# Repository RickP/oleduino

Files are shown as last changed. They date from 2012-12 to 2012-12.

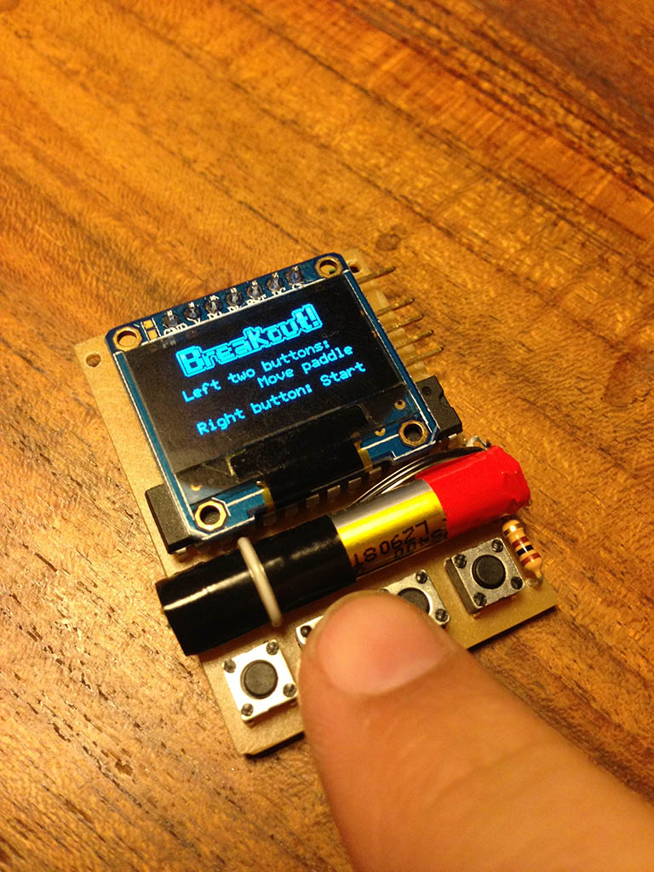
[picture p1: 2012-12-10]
Assembled_Device.jpg

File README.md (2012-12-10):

OLEDuino
--------

A cheap electronic name badge that can be programmed with the arduino ide. 
The ATMEGA 328 has to be preloaded with the Arduino Pro 8Mhz 3.3V bootloader.
Also chose that board when programming the badge with a 3.3V FTDI board.

All the analog ports are available for addons. 

* A source for the OLED: Search eBay for "128X64 OLED module" and pick the cheapest one with the 7 pin header on top
* A source for a battery: Any small 3.7V lithium polymer battery will do (like the ones for small RC helicopters)
* A source for the charger: http://www.ebay.com/itm/260581913847

OLEDuino

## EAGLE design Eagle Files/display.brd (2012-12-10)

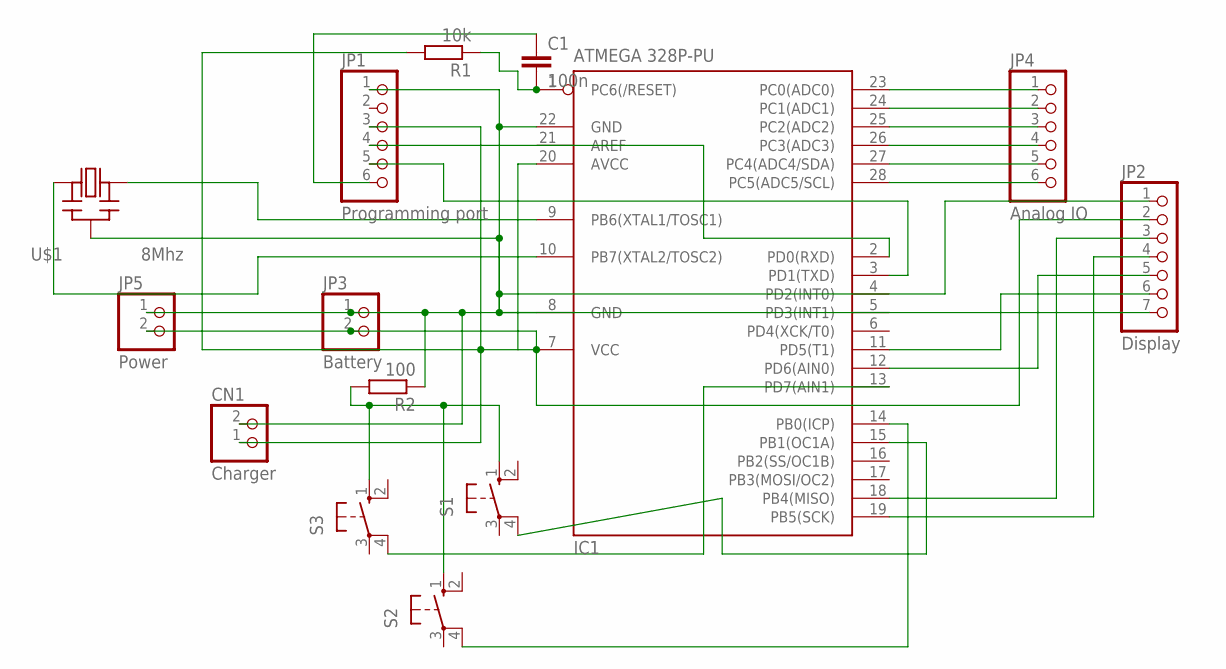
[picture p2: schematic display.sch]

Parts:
C1: 100n; C050-025X075
CN1: Charger; JST-PH-2-THM-RA
IC1: ATMEGA 328P-PU; DIL28-3
JP1: Programming port; 1X06/90
JP2: Display; 1X07
JP3: Battery; 1X02
JP4: Analog IO; 1X06-CLEAN
JP5: Power; 1X02
R1: 10k; 0204/7
R2: 100; 0204/7
S1, S3: 10-XX; B3F-10XX
S2: 10-XX; B3F-10XX; MPN B3F-1000
U$1: 8Mhz; CERM_OSC

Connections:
unnamed: IC1.23 (PC0(ADC0)), JP4.1
unnamed: IC1.10 (PB7(XTAL2/TOSC2)), U$1.P$1 (IN)
unnamed: IC1.19 (PB5(SCK)), JP2.4
unnamed: C1.2, IC1.1 (PC6(/RESET)), R1.1
unnamed: IC1.2 (PD0(RXD)), JP1.4
unnamed: IC1.3 (PD1(TXD)), JP1.5
unnamed: IC1.18 (PB4(MISO)), JP2.3
unnamed: CN1.1 (2), IC1.7 (VCC), IC1.20 (AVCC), JP1.3, JP2.2, JP3.2, JP5.2, R1.2
unnamed: IC1.15 (PB1(OC1A)), S1.4 (P1)
unnamed: IC1.13 (PD7(AIN1)), S3.4 (P1)
unnamed: C1.1, JP1.6
unnamed: R2.2, S1.1 (S), S2.1 (S), S3.1 (S)
unnamed: IC1.12 (PD6(AIN0)), JP2.5
unnamed: IC1.9 (PB6(XTAL1/TOSC1)), U$1.P$3 (OUT)
unnamed: IC1.11 (PD5(T1)), JP2.6
unnamed: IC1.14 (PB0(ICP)), S2.4 (P1)
unnamed: IC1.28 (PC5(ADC5/SCL)), JP4.6
unnamed: IC1.27 (PC4(ADC4/SDA)), JP4.5
unnamed: IC1.26 (PC3(ADC3)), JP4.4
unnamed: IC1.25 (PC2(ADC2)), JP4.3
unnamed: IC1.24 (PC1(ADC1)), JP4.2
unnamed: CN1.2 (1), IC1.8 (GND), IC1.22 (GND), JP1.1, JP2.1, JP2.7, JP3.1, JP5.1, R2.1, U$1.P$2 (GND)

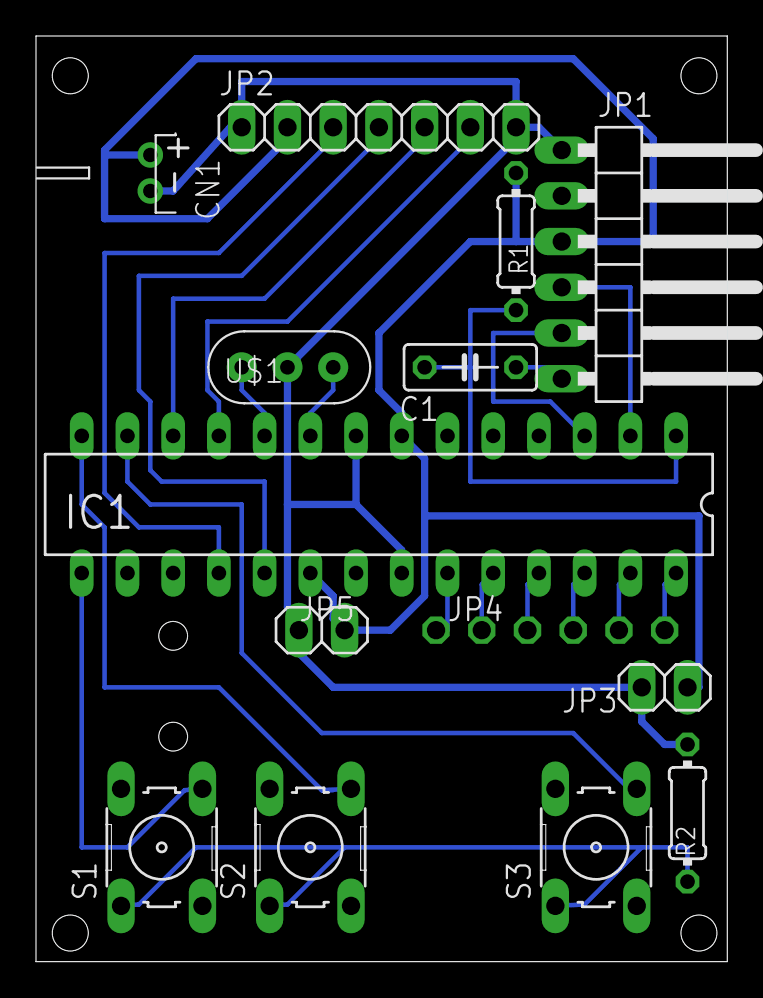
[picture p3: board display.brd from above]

Board: 2 copper layers, 38.4 x 51.4 mm, 14 parts (0 on the bottom side), 22 nets.

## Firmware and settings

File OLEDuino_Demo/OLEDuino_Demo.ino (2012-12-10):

 /*
 OLEDuino Demo
 Copyright (C) 2012 Rick Pannen

 The Breakout game is ported from Sebastian Goscik's version for hackvision

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
 
 This needs the u8glib from http://code.google.com/p/u8glib
 */

#include "U8glib.h"

U8GLIB_SSD1306_128X64 u8g(U8G_PIN_NONE, 5, 6);

const uint8_t title_1[] U8G_PROGMEM = {
0x00,0x07,0xFF,0x80,0x00,0x00,0x00,0x00,0x00,0x00,0x00,0x00,0x03,0xE0,0x00,
0x00,0x08,0x00,0x60,0x00,0x00,0x00,0x1F,0x00,0x00,0x00,0x03,0xF4,0x10,0x00,
0x00,0x0B,0xFF,0x10,0x00,0x00,0x00,0x20,0x80,0x00,0x00,0x04,0x09,0xD0,0x00,
0x00,0x0B,0x83,0xD0,0x00,0x00,0x00,0x2E,0xB8,0x00,0x00,0x05,0xE1,0xD0,0x00,
0x00,0x0B,0x83,0xD0,0x00,0x00,0x00,0x2E,0x44,0x00,0x00,0x05,0xE1,0xD0,0x00,
0x00,0x0B,0x83,0xD0,0x00,0x00,0x00,0x2E,0x34,0x00,0x00,0x05,0xE1,0xD0,0x00,
0x00,0x0B,0x83,0xCF,0xFF,0xF9,0xFF,0xAE,0x35,0xFF,0x7C,0xF9,0xE1,0xD0,0x00,
0x00,0x0B,0x83,0xC0,0x00,0x06,0x00,0x4E,0x66,0x00,0x83,0x01,0xE1,0xD0,0x00,
0x00,0x0B,0xFF,0x13,0xE7,0xF0,0xFF,0x0F,0xE0,0x7E,0x38,0x73,0xF9,0xD0,0x00,
0x00,0x0B,0xFF,0x13,0xE7,0xF0,0xFF,0x0F,0xC0,0x7E,0x38,0x73,0xF9,0xD0,0x00,
0x00,0x0B,0x83,0xDC,0x0E,0x0C,0x01,0xCF,0x80,0xE1,0x38,0x71,0xE1,0xD0,0x00,
0x00,0x0B,0x83,0xDC,0xCE,0x0C,0x01,0xCF,0xC0,0xE1,0x38,0x71,0xE1,0xD0,0x00,
0x00,0x0B,0x83,0xDD,0x2F,0xF0,0x7F,0xCE,0xE0,0xE1,0x38,0x71,0xE0,0x10,0x00,
0x00,0x0B,0x83,0xDD,0x2F,0xF0,0xFF,0xCE,0x70,0xE1,0x38,0x71,0xE0,0x10,0x00,
0x00,0x0B,0x83,0xDD,0x2E,0x00,0x81,0xCE,0x38,0xE1,0x38,0x71,0xE1,0xD0,0x00,
0x00,0x0B,0xFF,0x1D,0x27,0xFC,0xFE,0xCE,0x1C,0x7E,0x1F,0xC4,0x79,0xD0,0x00,
0x00,0x0B,0xFF,0x1D,0x17,0xFC,0x7E,0xCE,0x0C,0x7E,0x1F,0xCA,0x79,0xD0,0x00,
0x00,0x08,0x00,0x41,0x10,0x01,0x00,0x00,0xE1,0x00,0xC0,0x11,0x00,0x10,0x00,
0x00,0x07,0xFF,0xBE,0x0F,0xFE,0xFF,0xFF,0x1E,0xFF,0x3F,0xE0,0xFF,0xE0,0x00,
};

int leftButton = 9;
int rightButton = 8;
int enterButton = 7;

const byte width = 128;   //Width of screen
const byte height = 64;   //Hight of screen
int dx = -1;              //Initial movement of ball
int dy = -1;              //Initial movement of ball
int xb;                   //Balls starting possition
int yb;                   //Balls starting possition
boolean released;         //If the ball has been released by the player
byte xPaddle;             //X position of paddle
boolean isHit[5][12];     //Array of if bricks are hit or not
boolean bounced=false;    //Used to fix double bounce glitch
byte lives = 3;           //Amount of lives
byte level = 1;           //Current level
unsigned int score=0;     //Score for the game
unsigned int brickCount;  //Amount of bricks hit
byte pad1,pad2,pad3;       //Button press buffer used to stop pause repeating
byte oldpad1,oldpad2,oldpad3;
char text[16];            //General string buffer
boolean start=false;      //If in menu or in game
boolean gamemode=false;      //If in menu or in game
boolean initialDraw=false;//If the inital draw has happened
char initials[3];         //Initials used in high score
int divisor = 2;
int moveStep = 0;
int stringPos = 0;

//Ball Bounds used in collision detection
byte leftBall;
byte rightBall;
byte topBall;
byte bottomBall;

//Brick Bounds used in collision detection
byte leftBrick;
byte rightBrick;
byte topBrick;
byte bottomBrick;

long lastKeypress;

int lastButtonState;    // the debounce time;

void setup()
{ 
  pinMode(leftButton, INPUT);
  digitalWrite(leftButton, HIGH);
  pinMode(rightButton, INPUT);
  digitalWrite(rightButton, HIGH);
  pinMode(enterButton, INPUT);
  digitalWrite(enterButton, HIGH);
  
}

void movePaddle()
{
  //Move right
  if(xPaddle < width-20)
  {
    if(!digitalRead(rightButton))
    {  
      xPaddle++;
      lastKeypress = millis();
    }
  }

  //Move left
  if(xPaddle > 0)
  {
    if(!digitalRead(leftButton))
    {  
      xPaddle--;
      lastKeypress = millis();
    }
  } 
}

void moveBall()
{
  if(released)
  {
    //Move ball
    xb=xb + dx;
    yb=yb + dy;

    //Set bounds
    leftBall = xb;
    rightBall = xb+2;
    topBall = yb;
    bottomBall = yb+2;

    //Bounce off top edge
    if (yb<=0)
    {
      yb=2;
      dy=-dy;
    }

    //Lose a life if bottom edge hit
    if (yb>=70)
    {
      xPaddle = 54;
      yb=60; 
      released = false;
      lives--;
      drawLives();
      if (random(0, 2) == 0) {
        dx = 1;
      } 
      else {
        dx = -1;
      }
    }

    //Bounce off left side
    if (xb<=0)
    {
      xb=2;
      dx=-dx;
    }

    //Bounce off right side
    if (xb>=width-2)
    {
      xb=width-4;
      dx=-dx;
    }
    //Bounce off paddle
    if (xb+1>=xPaddle && xb<=xPaddle+20 && yb+2==63){
      dy=-dy;
      dx=((xb-(xPaddle+10))/2); //Applies spin on the ball
    }

    //Bounce off Bricks
    for (byte row = 0; row < 3; row++) {
      for (byte column = 0; column < 12; column++) {
        if (!isHit[row][column]){

          //Sets Brick bounds
          leftBrick = 10*column;
          rightBrick = 10*column+10;
          topBrick = 6*row+6;
          bottomBrick = 6*row+13;

          //If A collison has occured
          if (topBall <= bottomBrick && bottomBall>=topBrick && leftBall<=rightBrick && rightBall >=leftBrick){
            brickCount++;
            score += (level*10);
            isHit[row][column] = true;
            u8g.setColorIndex(1);
            u8g.drawBox(10*column ,2+6*row,8,4);

            //Vertical collision
            if (bottomBall>bottomBrick || topBall<topBrick){
              //Only bounce once each ball move
              if(!bounced){
                dy=-dy;
                yb+=dy;
                bounced=true;
              } 
            }

            //Hoizontal collision
            if (leftBall<leftBrick || rightBall>rightBrick){

              //Only bounce once brick each ball move
              if(!bounced){
                dx=-dx;
                xb+=dx;
                bounced=true;
              } 
            }
          }
        }
      }
    }
    //Reset Bounce
    bounced=false;
  }
  else{
    //Ball follows paddle
    xb=xPaddle+9;

    //Release ball if FIRE pressed
    pad3 = !digitalRead(enterButton);
    if(pad3 == 1 && oldpad3==0){  
      released=true;
      lastKeypress = millis();
      
      //Apply random direction to ball on release
      if (random(0, 2) == 0) {
        dx = 1;
      } 
      else {
        dx = -1;
      }
      //Makes sure the ball heads upwards 
      dy = -1;
    }
    oldpad3=pad3; 
  }
}

void drawBall()
{
  if (moveStep++ > divisor) {
    moveBall();
    moveStep = 0;
  }

  u8g.setColorIndex(1);
  u8g.drawPixel(xb,yb);
  u8g.drawPixel(xb+1,yb);
  u8g.drawPixel(xb,yb+1);
  u8g.drawPixel(xb+1,yb+1);
}

void drawPaddle()
{
  movePaddle();
  u8g.setColorIndex(1);
  u8g.drawBox(xPaddle,63,19,1);
}

void drawLives()
{
  sprintf(text, "LIVES:%u", lives);
  u8g.setColorIndex(1);
  u8g.setFont(u8g_font_04b_24);
  u8g.drawStr(0, 5, text);
}

void drawGameOver()
{
  u8g.setColorIndex(1);
  u8g.setFont(u8g_font_04b_24);
  u8g.drawStr(52, 54, "Game Over");
}

void drawScore()
{
  sprintf(text, "SCORE:%u", score);
  u8g.setColorIndex(1);
  u8g.setFont(u8g_font_04b_24);
  u8g.drawStr(80, 5, text);
}

void newLevel(){
  //Alter various variables to reset the game
  xPaddle = 50;
  yb=60;
  brickCount=0;
  released=false;
  
  //resets their values
  u8g.setColorIndex(1);
  for (byte row = 0; row < 3; row++) {
    for (byte column = 0; column < 12; column++) {
      isHit[row][column] = false;
    }
  }
}

void drawBricks() {
  u8g.setColorIndex(1);
  for (byte row = 0; row < 3; row++) {
    for (byte column = 0; column < 12; column++) {
      if (!isHit[row][column]) {
        u8g.drawBox(10*column ,6+6*row,8,4);
      }
    }
  }
}

boolean titleScreen() {
  
  u8g.setColorIndex(1);
  //Draws the main title
  u8g.drawBitmapP(4, 0, 15, 19, title_1);

  u8g.setColorIndex(1);
  if (score > 0) {
    u8g.setFont(u8g_font_tpssb);
    u8g.drawStr(30, 35, F("GAME OVER!"));
    sprintf(text, "SCORE:%u", score);
    u8g.drawStr(30, 48, text);
  } else {
    u8g.setFont(u8g_font_6x12);
    u8g.drawStr(10, 35, F("Left two buttons:"));
    u8g.drawStr(57, 45, F("Move paddle"));
  }
  
  u8g.setFont(u8g_font_6x12);
  u8g.drawStr(10, 60, F("Right button: Start"));

  pad3 = !digitalRead(enterButton);
  if(pad3 == 1 && oldpad3==0) {
    newLevel();
    score = 0;
    lives = 3;
    lastKeypress = millis();
    return true;
  }
  oldpad3 = pad3;
  
  return false;
}

void game()
{  
  if (lives>0){
    
    drawLives();
    drawScore();
    drawBricks();
    drawPaddle();
    drawBall();

    if(brickCount==36){
      level++;
      newLevel(); 
    }
  }
  else{
    delay(1000);
    start=false;
    // gamemode=false;
  }
}

void displayName() {
  
  u8g.setFont(u8g_font_fub20);
  u8g.drawStr(0, 30, "Rick P.");
  u8g.drawLine(0, 32, 128, 32);
  u8g.setFont(u8g_font_unifont);
  u8g.drawStr( 20, 44, "attraktor e.v.");
  pad1 = !digitalRead(leftButton);
  if(pad1 == 1 && oldpad1==0) {
    gamemode = true;
    lastKeypress = millis();
  }
  oldpad1 = pad1;
  
  pad2 = !digitalRead(rightButton);
  if(pad2 == 1 && oldpad2==0) {
    gamemode = true;
    lastKeypress = millis();
  }
  oldpad1 = pad1;
  
  pad3 = !digitalRead(enterButton);
  if(pad3 == 1 && oldpad3==0) {
    gamemode = true;
    lastKeypress = millis();
  }
  oldpad3 = pad3;
}

void loop() 
{
  u8g.firstPage();
  do {
    if (gamemode) {
      if (start) {
        game();
      } else {
        start = titleScreen();
      }
      if (millis() - lastKeypress > 15000) {
        gamemode = false;
      }
    } else {
      displayName();
    }
  }
  while(u8g.nextPage());
}

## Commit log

2012-12-10 removed one button
    [display.brd, display.sch]
2012-12-10 changed labes and positioning
    [display.brd, display.sch]
2012-12-10 changed labels and positioning
    [display.brd]
2012-12-10 fixed a typo
    [display.brd, display.sch]
